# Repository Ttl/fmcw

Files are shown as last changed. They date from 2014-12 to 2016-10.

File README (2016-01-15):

Frequency modulated radar hardware, firmware and processing files.

For more information see:

http://hforsten.com/6-ghz-frequency-modulated-radar.html

and

http://hforsten.com/homemade-synthetic-aperture-radar.html

List of contents:

hardware: Contains KiCad schematic and board files. Made using KiCad version 2014-10-17 and might not open with a too old version.

firmware: Firmware for the Freescale Kinetis KL26Z microcontroller. Should be opened using Kinetis Design Studio (http://www.freescale.com/webapp/sps/site/prod_summary.jsp?code=KDS_IDE).

Firmware depends on mcuoneclipse components available at here: http://sourceforge.net/projects/mcuoneclipse/files/PEx%20Components/

processing: PC code for using the radar and processing the resulting data.
"fmcw.py" uses the radar and logs the data.
"fmcw_process.py" process the recorded data and plots time-range plot of them.
"list_plot.py" plots individual sweep captures from the recorded data for debugging purposes.

simulations: CST Microwave studio files.

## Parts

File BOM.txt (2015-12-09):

Digikey product codes

Capacitors:
10nF: 1276-1500-1-ND
0.5pF: 399-6157-1-ND
0.3pF: 399-6155-1-ND
100pF: 311-1024-1-ND
10pF: 1276-1139-1-ND
10uF: 311-1460-1-ND
2.2uF: 1276-1040-1-ND
4.7nF: 1276-1571-1-ND
1nF: 1276-1916-1-ND
22uF: 1276-2910-1-ND
1.8pF: 490-3089-1-ND
33pF: 1276-1272-1-ND
100n: 311-1697-1-ND

Inductors:
0.6nH: 445-3031-1-ND
1uH: 1276-6207-1-ND

Resistors:
1% tolerance
ATTENUATOR 7 DB 50 OHM 0805 SMD: PAT127CT-ND

Diodes:
DIODE SCHOTTKY 40V 0.2A SOT323: BAS40WT-TPCT-ND

Actives:
IC MIXER 4.5-9GHZ UP/DWN 8MSOP: 1127-1004-1-ND
IC RF PWR AMP 802.11A/N 16-QFN: SST11LP12-QCFCT-ND
IC MMIC VCO W/BUFF AMP 4X4QFN: 1127-1036-1-ND
IC AMP 5GHZ LNA 6QFN: 863-1398-1-ND

IC OPAMP GP 18MHZ RRO 16SSOP: LTC6242CGN#PBF-ND
IC OPAMP GP 215MHZ RRO TSOT23-6: LT6230CS6#TRMPBFCT-ND
IC OPAMP GP 1.4MHZ RRO SOT23-5: 497-7687-1-ND

IC REG MULTI CONFIG ADJ SOT23-6: 296-35223-1-ND
IC REG BUCK SYNC 3.3V SOT23-5: SC189ZSKCT-ND
IC REG LDO 3.3V 0.15A SC59-3: 863-1507-1-ND
IC REG LDO 3V 0.25A SOT23-3: MCP1700T-3002E/TTCT-ND

IC DGTL POT 10K 128TAPS SC70-6: MCP4017T-103E/LTCT-ND
IC MCU ARM 128KB FLASH 48QFN: MKL26Z128VFT4-ND
MOSFET P-CH 50V 130MA SOT-23: BSS84CT-ND
CRYSTAL 8MHZ 18PF SMD: 887-1448-1-ND

Connectors:
CONN SMA JACK 50 OHM EDGE MNT: CONSMA003.062-ND
SIL VERTICAL PC TAIL PIN HEADER: 952-2270-ND

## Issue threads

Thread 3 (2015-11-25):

Missing component libraries

penguin359, 2015-11-25:
It appears that a few components have changed since the 2014 release of the libraries and the pins of the new components don't match up. In particular, resistors and capacitors are shorter breaking the wire connections to the pins. The other components that are different are the four connectors used across the two sheets, wlan_radar.sch and mcu.sch. In the case of the connectors, it appears that their names have changed from CONN_2 and CONN_6 to CONN_01X02 and CONN_01X06. Updating the schematic files with the correct names makes the components show up, but their pin positions still don't line up so the wires have to be re-drawn.

I've re-attached all the wires to the appropriate pins to match with the updated components and the ERC now shows only three errors/warnings that appear have been there with the original schematic. However, I'd prefer to just keep the original schematic and it's library of components. Normally, a cached library, wlan_radar-cache.lib in this case, is created to house all the components used in a design. This allows the design to move across systems that might have a different set of libraries installed. Do you have a copy of the original library cache and can you include it in the Git repository so that the design files will still be intact regardless of the set of libraries installed on the local system?

Ttl, 2015-11-25:
I added the library cache file.

Closed 2015-11-25.

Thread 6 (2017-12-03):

radar range

mkeyno, 2017-12-03:
hi
sorry to open ticket for question , but have you run any test range ?what is the maximum of motion detection range ?
BR

Ttl, 2017-12-03:
Depends on the antennas but probably under 100 m even with good antennas.

This radar doesn't have very good performance and I don't recommend using it. See: https://github.com/Ttl/fmcw3 for a much better radar.

Closed 2017-12-03.

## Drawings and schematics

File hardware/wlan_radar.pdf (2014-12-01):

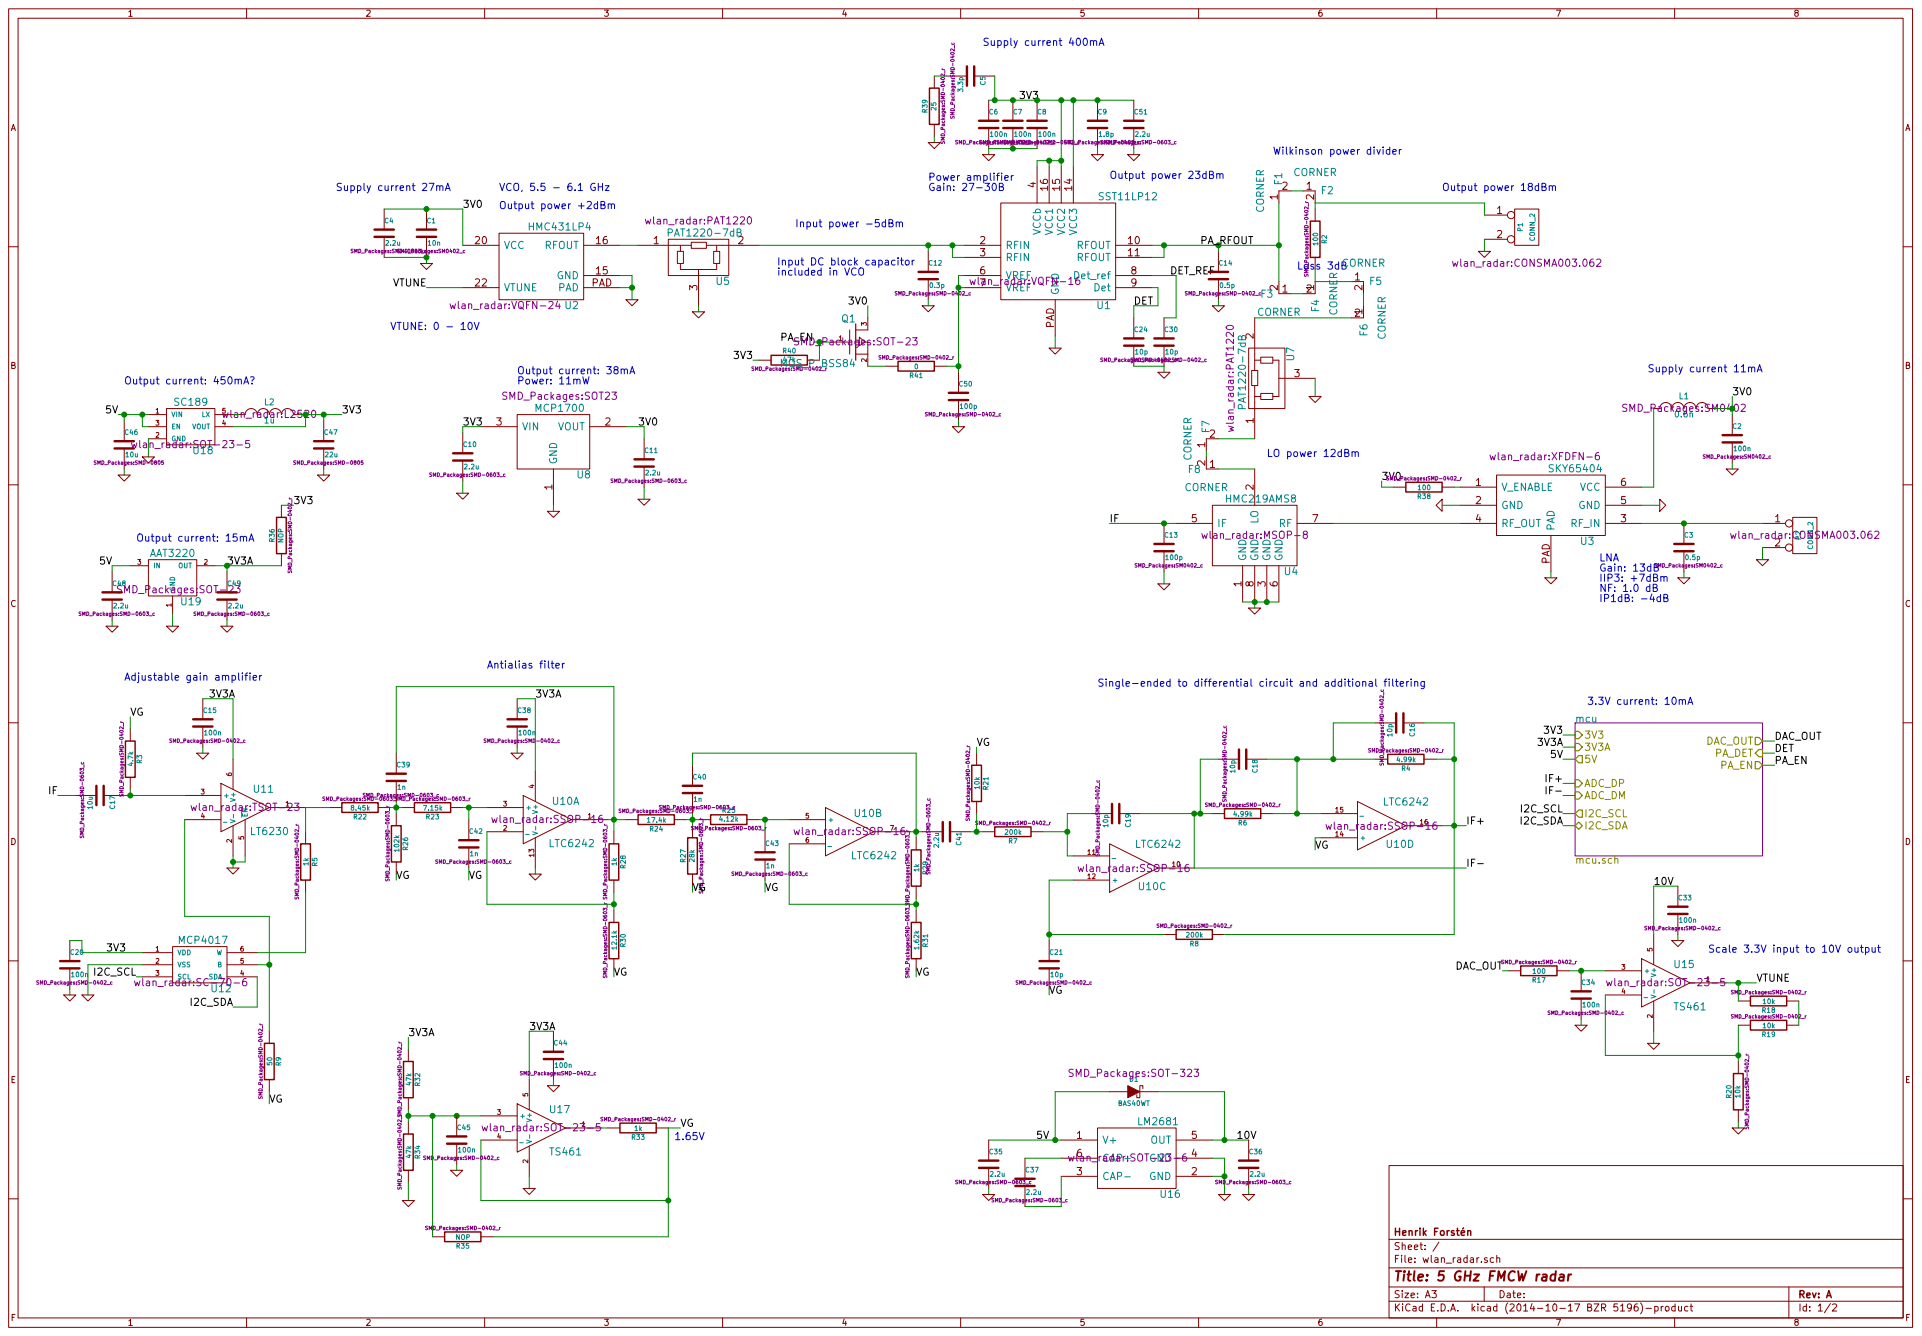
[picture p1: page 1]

4 VREF 6 VREF 7 Det_ref 8 Det 9 RFOUT 10 RFOUT 11 VCC3 14 VCC2 15 VCC1 16 GND PADU1SST11LP12

Input DC block capacitor
included in VCO

Scale 3.3V input to 10V output R17

File: wlan_radar.sch Sheet: / Henrik Forstén

Id: 1/2 Title: 5 GHz FMCW radar

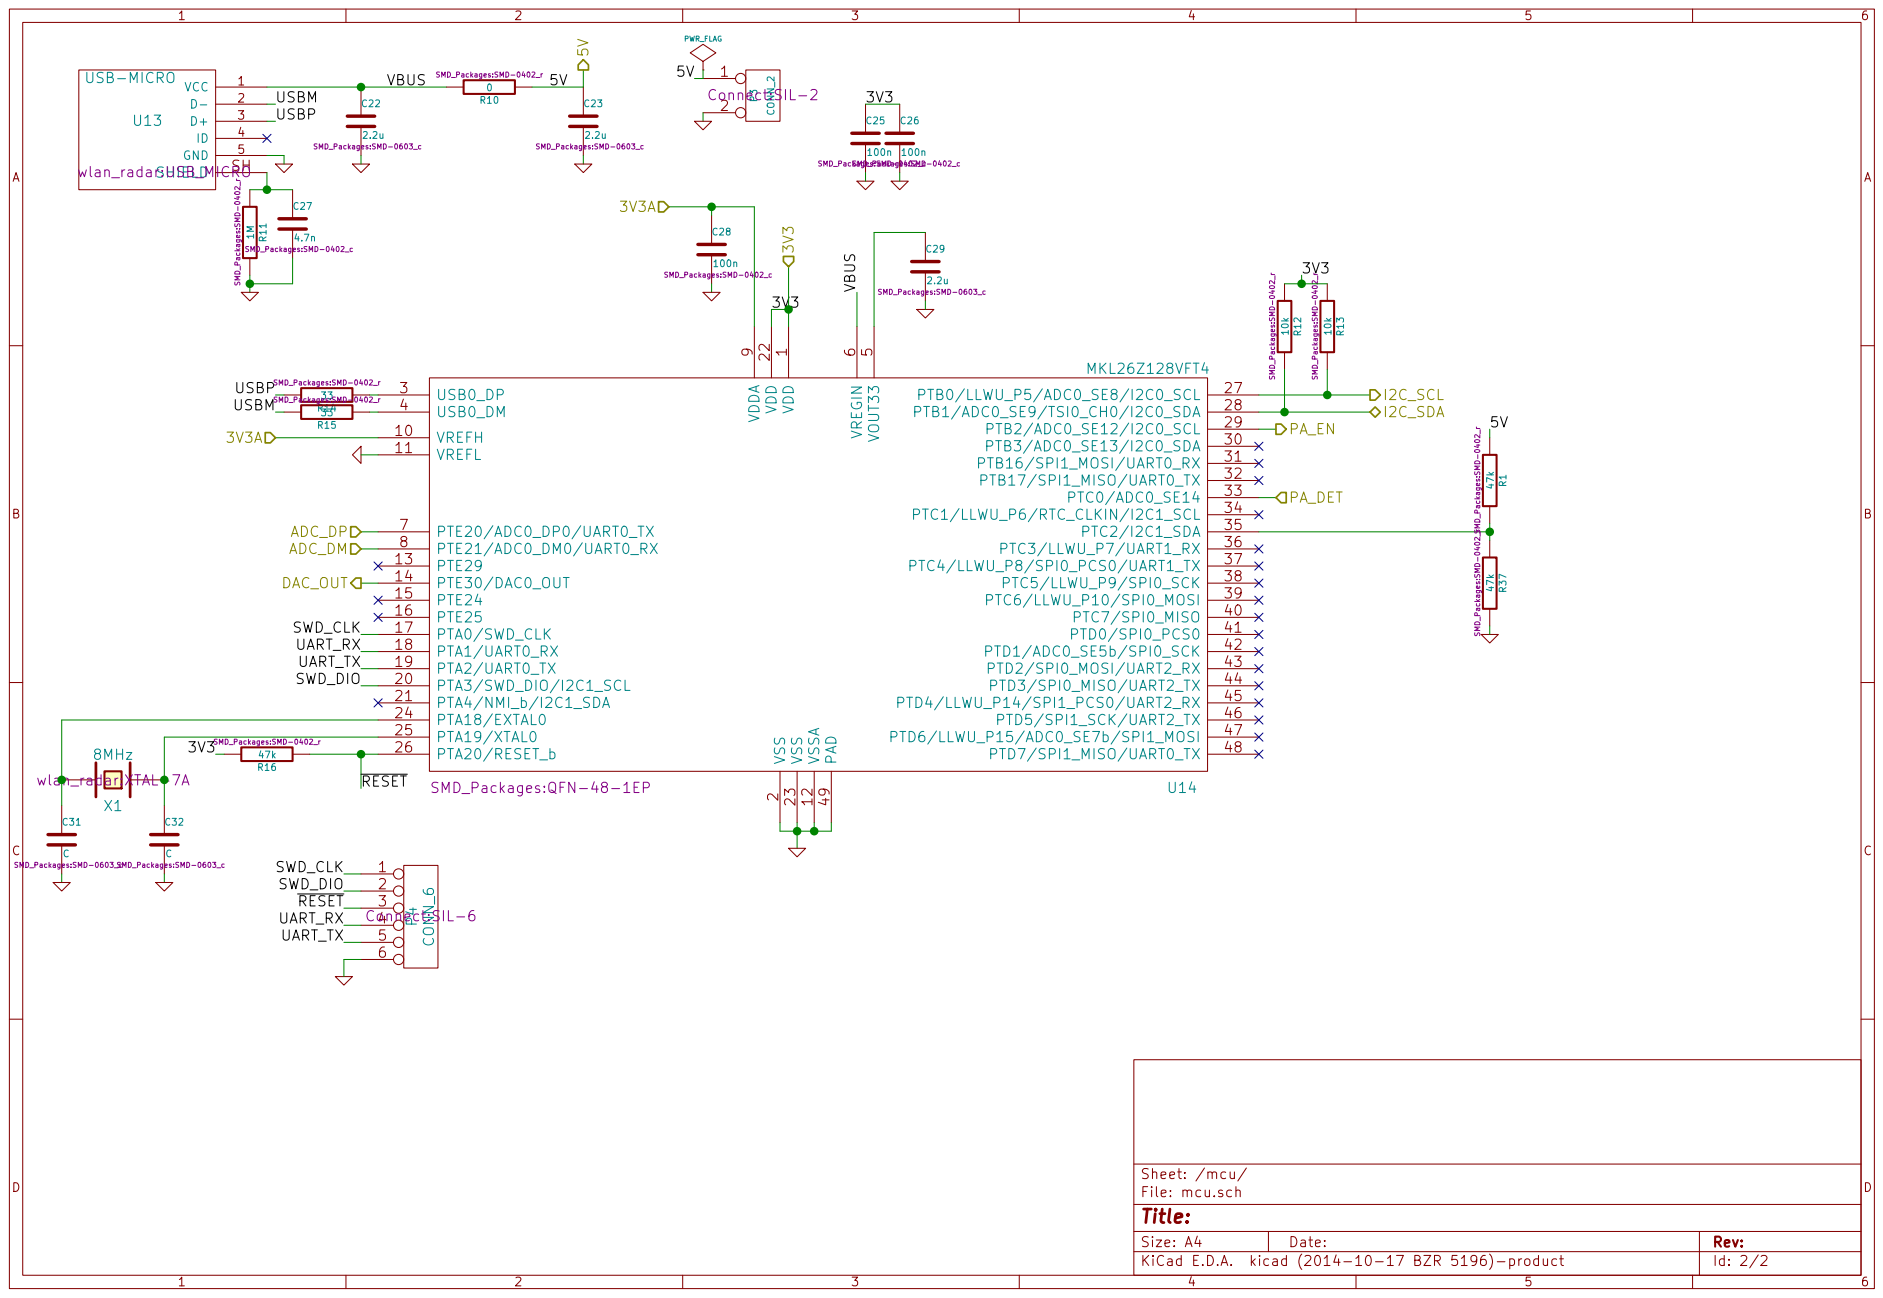
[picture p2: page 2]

9 VREFH 10 PTA3/SWD_DIO/I2C1_SCL 20 PTB3/ADC0_SE13/I2C0_SDA 30 PTC7/SPI0_MISO 40 VREFL 11 PTA4/NMI_b/I2C1_SDA 21 PTB16/SPI1_MOSI/UART0_RX 31 PTD0/SPI0_PCS0 41 VSSA 12 VDD 22

Id: 2/2 Title: File: mcu.sch Sheet: /mcu/ VDD

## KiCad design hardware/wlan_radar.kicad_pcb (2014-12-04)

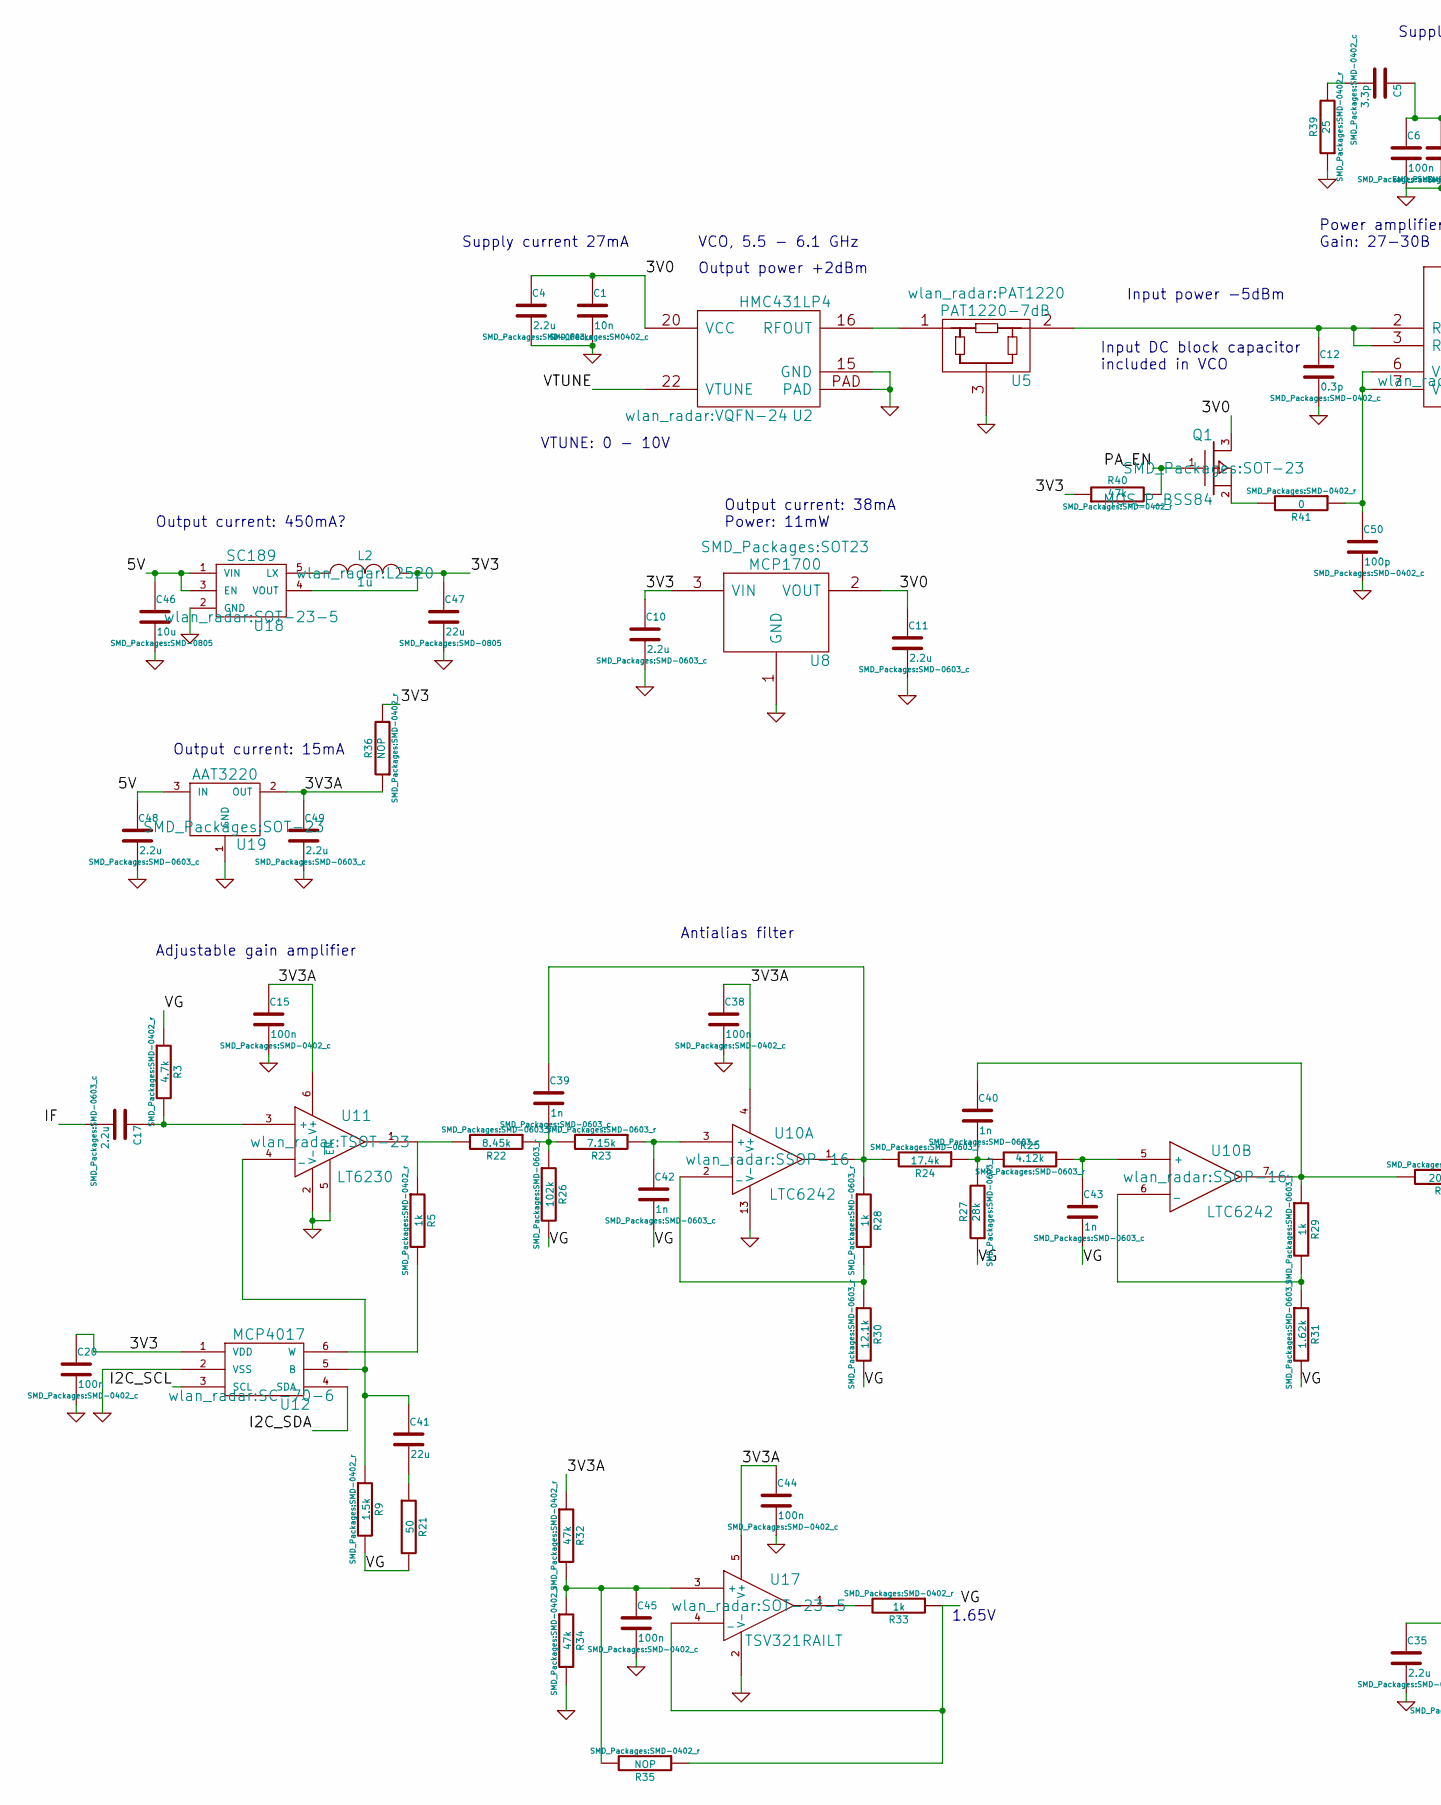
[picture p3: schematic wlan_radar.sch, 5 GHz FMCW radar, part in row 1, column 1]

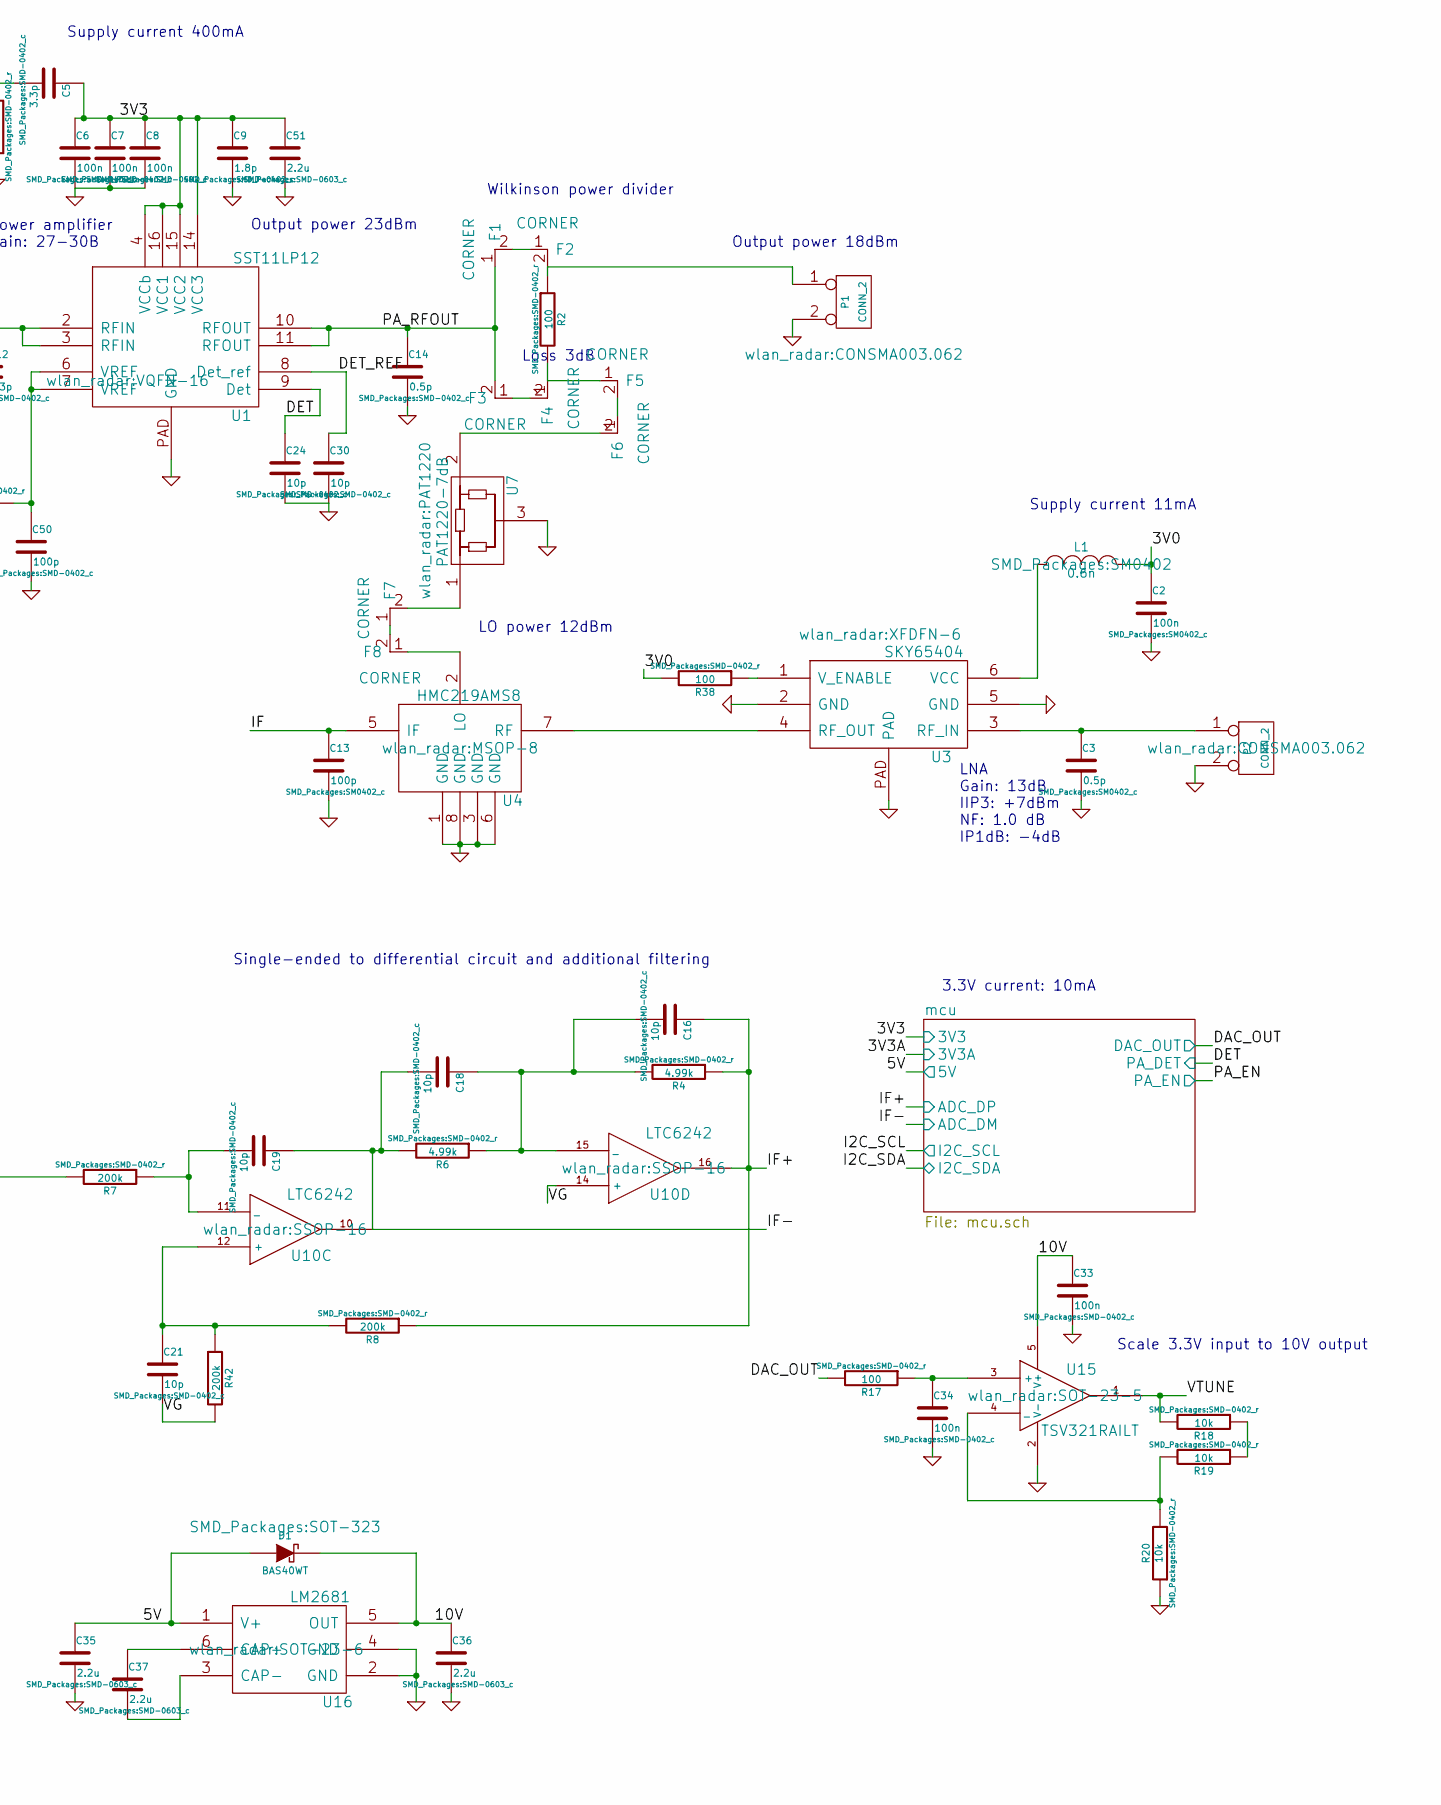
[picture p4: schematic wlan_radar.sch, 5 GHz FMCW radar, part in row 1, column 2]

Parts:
C1: 10n; SM0402_c
C2: 100n; SM0402_c
C3: 0.5p; SM0402_c
C4, C10, C11, C17, C35, C36, C37, C48, C49, C51: 2.2u; SMD-0603_c
C5: 3.3p; SMD-0402_c
C6, C7, C8, C15, C20, C33, C34, C38, C44, C45: 100n; SMD-0402_c
C9: 1.8p; SMD-0402_c
C12: 0.3p; SMD-0402_c
C13: 100p; SM0402_c
C14: 0.5p; SMD-0402_c
C16, C18, C19, C21, C24, C30: 10p; SMD-0402_c
C39, C40, C42, C43: 1n; SMD-0603_c
C41, C47: 22u; SMD-0805
C46: 10u; SMD-0805
C50: 100p; SMD-0402_c
D1: BAS40WT; SOT-323
F1, F2, F3, F4: CORNER; miter_0.179_90deg
F5, F6, F7, F8: CORNER; MITER_0.350mm_90deg
L1: 0.6n; SM0402
L2: 1u; L2520
P1, P2: CONN_2; CONSMA003.062
Q1: MOS_P_BSS84; SOT-23
R2, R17, R38: 100; SMD-0402_r
R3: 4.7k; SMD-0402_r
R4, R6: 4.99k; SMD-0402_r
R5, R33: 1k; SMD-0402_r
R7, R8, R42: 200k; SMD-0402_r
R9: 1.5k; SMD-0402_r
R18, R19, R20: 10k; SMD-0402_r
R21: 50; SMD-0402_r
R22: 8.45k; SMD-0603_r
R23: 7.15k; SMD-0603_r
R24: 17.4k; SMD-0603_r
R25: 4.12k; SMD-0603_r
R26: 102k; SMD-0603_r
R27: 28k; SMD-0603_r
R28, R29: 1k; SMD-0603_r
R30: 12.1k; SMD-0603_r
R31: 1.62k; SMD-0603_r
R32, R34, R40: 47k; SMD-0402_r
R35, R36: NOP; SMD-0402_r
R39: 25; SMD-0402_r
R41: 0; SMD-0402_r
U1: SST11LP12; VQFN-16
U2: HMC431LP4; VQFN-24
U3: SKY65404; XFDFN-6
U4: HMC219AMS8; MSOP-8
U5, U7: PAT1220-7dB; PAT1220
U8: MCP1700; SOT23
U10: LTC6242; SSOP-16
U11: LT6230; TSOT-23
U12: MCP4017; SC-70-6
U15, U17: TSV321RAILT; SOT-23-5
U16: LM2681; SOT-23-6
U18: SC189; SOT-23-5
U19: AAT3220; SOT-23

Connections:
/3V0: C1.1, C2.1, C4.1, C11.1, L1.2, Q1.3 (D), R38.2, U2.20 (VCC), U8.2 (VOUT)
/10V: C33.1, C36.1, D1.3 (K), U15.5 (V+), U16.5 (OUT)
/DET_REF: C30.1, U1.8 (Det_ref)
/IF: C13.1, C17.2, U4.5 (IF)
/PA_RFOUT: C14.1, F1.1, F3.2, U1.10 (RFOUT), U1.11 (RFOUT)
/VG: C21.2, C42.2, C43.2, R3.1, R9.2, R21.2, R26.2, R27.1, R30.2, R31.2, R33.1, R35.1, R42.2, U10.14 (+), U17.4 (_)
/VTUNE: R18.2, U2.22 (VTUNE), U15.1
/mcu/3V3: C5.1, C6.1, C7.1, C8.1, C9.1, C10.1, C20.1, C47.1, C51.1, L2.2, R36.2, R40.1, U1.4 (VCCb), U1.14 (VCC3), U1.15 (VCC2), U1.16 (VCC1), U8.3 (VIN), U12.1 (VDD), U18.4 (VOUT); also elsewhere on the board
/mcu/3V3A: C15.1, C38.1, C44.1, C49.1, R32.1, R36.1, U10.4 (V+), U11.6 (V+), U17.5 (V+), U19.2 (OUT); also elsewhere on the board
/mcu/5V: C35.1, C46.1, C48.1, D1.1 (A), U16.1 (V+), U18.1 (VIN), U18.3 (EN), U19.3 (IN); also elsewhere on the board
/mcu/ADC_DM: C18.2, C19.1, R6.2, U10.10; also elsewhere on the board
/mcu/ADC_DP: C16.1, R4.1, R8.1, U10.16; also elsewhere on the board
/mcu/DAC_OUT: R17.2; also elsewhere on the board
/mcu/I2C_SCL: U12.3 (SCL); also elsewhere on the board
/mcu/I2C_SDA: U12.4 (SDA); also elsewhere on the board
/mcu/PA_DET: C24.1, U1.9 (Det); also elsewhere on the board
/mcu/PA_EN: Q1.1 (G), R40.2; also elsewhere on the board
GND: C1.2, C2.2, C3.2, C4.2, C6.2, C7.2, C8.2, C9.2, C10.2, C11.2, C12.2, C13.2, C14.2, C15.2, C20.2, C24.2, C30.2, C33.2, C34.2, C35.2, C36.2, C38.2, C44.2, C45.2, C46.2, C47.2, C48.2, C49.2, C50.2, C51.2, P1.2 (PM), P2.2 (PM), R20.1, R34.2, R39.1, U1.PAD (GND), U2.15 (GND), U2.PAD, U3.2 (GND), U3.5 (GND), U3.PAD, U4.1 (GND), U4.3 (GND), U4.6 (GND), U4.8 (GND), U5.3, U7.3, U8.1 (GND), U10.13 (V-), U11.2 (V-), U11.5 (~EN), U12.2 (VSS), U15.2 (V-), U16.2 (GND), U16.4 (GND), U17.2 (V-), U18.2 (GND), U19.1 (GND); also elsewhere on the board
unnamed: C3.1, P2.1, U3.3 (RF_IN)
unnamed: C5.2, R39.2
unnamed: C12.1, U1.2 (RFIN), U1.3 (RFIN), U5.2
unnamed: C16.2, C18.1, R4.2, R6.1, U10.15 (_)
unnamed: C17.1, R3.2, U11.3 (+)
unnamed: C19.2, R7.1, U10.11 (_)
unnamed: C21.1, R8.2, R42.1, U10.12 (+)
unnamed: C34.1, R17.1, U15.3 (+)
unnamed: C37.1, U16.6 (CAP+)
unnamed: C37.2, U16.3 (CAP-)
unnamed: C39.1, R24.2, R28.1, U10.1
unnamed: C39.2, R22.1, R23.2, R26.1
unnamed: C40.1, R7.2, R29.1, U10.7
unnamed: C40.2, R24.1, R25.1, R27.2
unnamed: C41.1, R9.1, U11.4 (_), U12.5 (B)
unnamed: C41.2, R21.1
unnamed: C42.1, R23.1, U10.3 (+)
unnamed: C43.1, R25.2, U10.5 (+)
unnamed: C45.1, R32.2, R34.1, R35.2, U17.3 (+)
unnamed: C50.1, R41.1, U1.6 (VREF), U1.7 (VREF)
unnamed: F1.2, F2.1
unnamed: F2.2, P1.1, R2.1
unnamed: F3.1, F4.2
unnamed: F4.1, F5.1, R2.2
unnamed: F5.2, F6.1
unnamed: F6.2, U7.2
unnamed: F7.1, F8.2
unnamed: F7.2, U7.1
unnamed: F8.1, U4.2 (LO)
unnamed: L1.1, U3.6 (VCC)
unnamed: L2.1, U18.5 (LX)
unnamed: Q1.2 (S), R41.2
unnamed: R5.2, U12.6 (W)
unnamed: R18.1, R19.1
unnamed: R19.2, R20.2, U15.4 (_)
unnamed: R5.1, R22.2, U11.1
unnamed: R28.2, R30.1, U10.2 (_)
unnamed: R29.2, R31.1, U10.6 (_)
unnamed: R33.2, U17.1
unnamed: R38.1, U3.1 (V_ENABLE)
unnamed: U2.16 (RFOUT), U5.1
unnamed: U3.4 (RF_OUT), U4.7 (RF)

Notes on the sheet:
VCO, 5.5 - 6.1 GHz
Output power +2dBm
Wilkinson power divider
Power amplifier Gain: 27-30B
Input power -5dBm
Output power 23dBm
Loss 3dB
Output power 18dBm
LO power 12dBm
LNA Gain: 13dB IIP3: +7dBm NF: 1.0 dB IP1dB: -4dB
Supply current 400mA
Supply current 27mA
VTUNE: 0 - 10V
Supply current 11mA
Output current: 38mA Power: 11mW
Scale 3.3V input to 10V output
1.65V
Adjustable gain amplifier
Antialias filter
Single-ended to differential circuit and additional filtering
Output current: 15mA
Output current: 450mA?
Input DC block capacitor included in VCO
3.3V current: 10mA

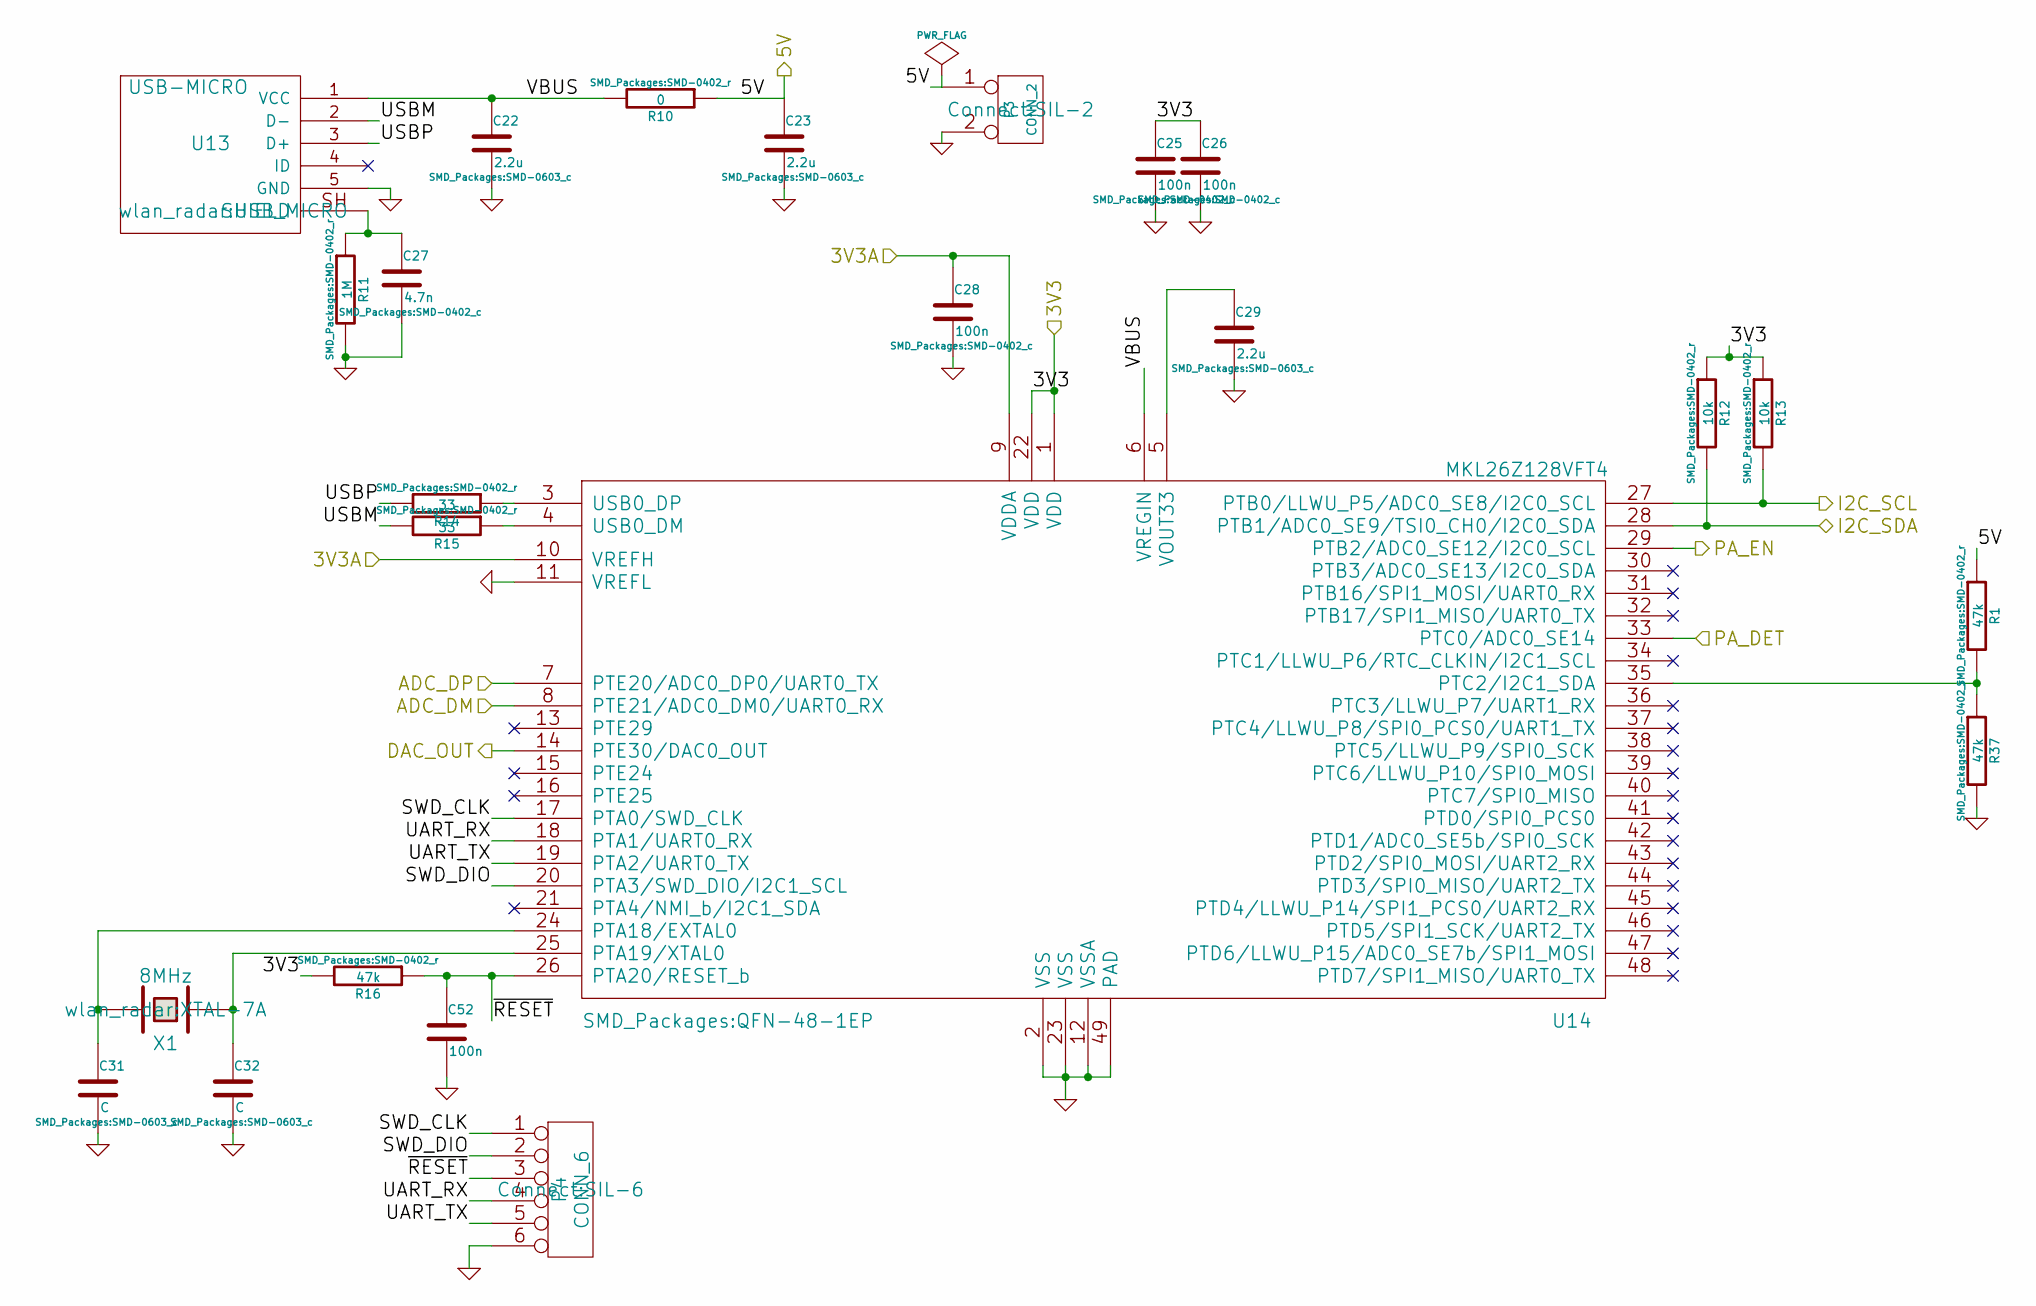
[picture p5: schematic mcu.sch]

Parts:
C22, C23, C29: 2.2u; SMD-0603_c
C25, C26, C28, C52: 100n; SMD-0402_c
C27: 4.7n; SMD-0402_c
C31, C32: C; SMD-0603_c
P3: CONN_2; SIL-2
P4: CONN_6; SIL-6
R1, R16, R37: 47k; SMD-0402_r
R10: 0; SMD-0402_r
R11: 1M; SMD-0402_r
R12, R13: 10k; SMD-0402_r
R14, R15: 33; SMD-0402_r
U13: USB-MICRO; USB_MICRO
U14: MKL26Z128VFT4; QFN-48-1EP
X1: 8MHz; XTAL-7A

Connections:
/mcu/3V3: C25.1, C26.1, R12.1, R13.1, R16.2, U14.1 (VDD), U14.22 (VDD); also elsewhere on the board
/mcu/3V3A: C28.1, U14.9 (VDDA), U14.10 (VREFH); also elsewhere on the board
/mcu/5V: C23.1, P3.1, R1.1, R10.1; also elsewhere on the board
/mcu/ADC_DM: U14.8 (PTE21/ADC0_DM0/UART0_RX); also elsewhere on the board
/mcu/ADC_DP: U14.7 (PTE20/ADC0_DP0/UART0_TX); also elsewhere on the board
/mcu/DAC_OUT: U14.14 (PTE30/DAC0_OUT); also elsewhere on the board
/mcu/I2C_SCL: R13.2, U14.27 (PTB0/LLWU_P5/ADC0_SE8/I2C0_SCL); also elsewhere on the board
/mcu/I2C_SDA: R12.2, U14.28 (PTB1/ADC0_SE9/TSI0_CH0/I2C0_SDA); also elsewhere on the board
/mcu/PA_DET: U14.33 (PTC0/ADC0_SE14); also elsewhere on the board
/mcu/PA_EN: U14.29 (PTB2/ADC0_SE12/I2C0_SCL); also elsewhere on the board
/mcu/SWD_CLK: P4.1, U14.17 (PTA0/SWD_CLK)
/mcu/SWD_DIO: P4.2, U14.20 (PTA3/SWD_DIO/I2C1_SCL)
/mcu/UART_RX: P4.4, U14.18 (PTA1/UART0_RX)
/mcu/UART_TX: P4.5, U14.19 (PTA2/UART0_TX)
/mcu/USBM: R15.2, U13.2 (D-)
/mcu/USBP: R14.2, U13.3 (D+)
/mcu/VBUS: C22.1, R10.2, U13.1 (VCC), U14.6 (VREGIN)
/mcu/~RESET: C52.1, P4.3, R16.1, U14.26 (PTA20/RESET_b)
GND: C22.2, C23.2, C25.2, C26.2, C27.2, C28.2, C29.2, C31.2, C32.2, C52.2, P3.2 (PM), P4.6, R11.2, R37.2, U13.5 (GND), U14.2 (VSS), U14.11 (VREFL), U14.12 (VSSA), U14.23 (VSS), U14.49 (PAD); also elsewhere on the board
unnamed: C27.1, R11.1, U13.SH (SHIELD)
unnamed: C29.1, U14.5 (VOUT33)
unnamed: C31.1, U14.24 (PTA18/EXTAL0), X1.2
unnamed: C32.1, U14.25 (PTA19/XTAL0), X1.1
unnamed: R1.2, R37.1, U14.35 (PTC2/I2C1_SDA)
unnamed: R14.1, U14.3 (USB0_DP)
unnamed: R15.1, U14.4 (USB0_DM)

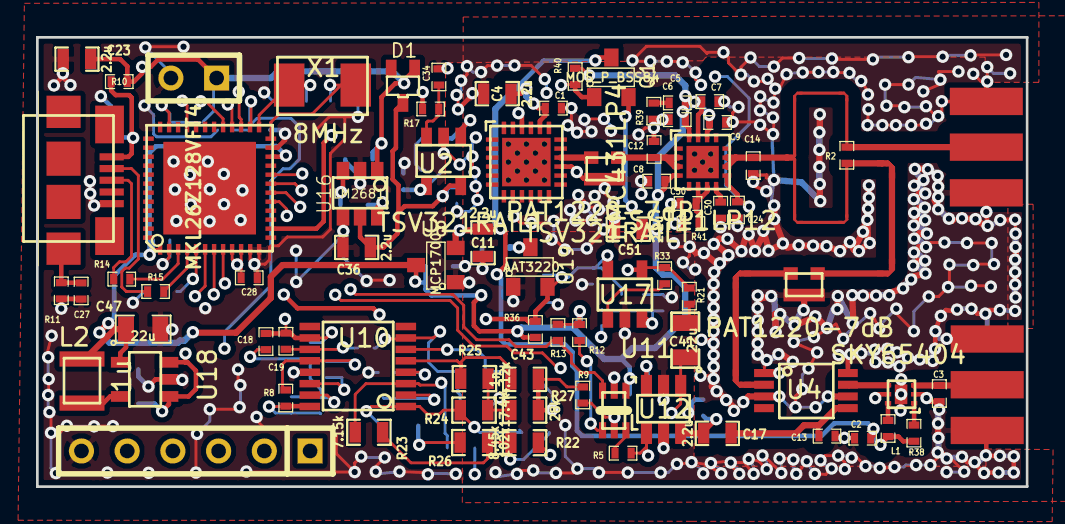
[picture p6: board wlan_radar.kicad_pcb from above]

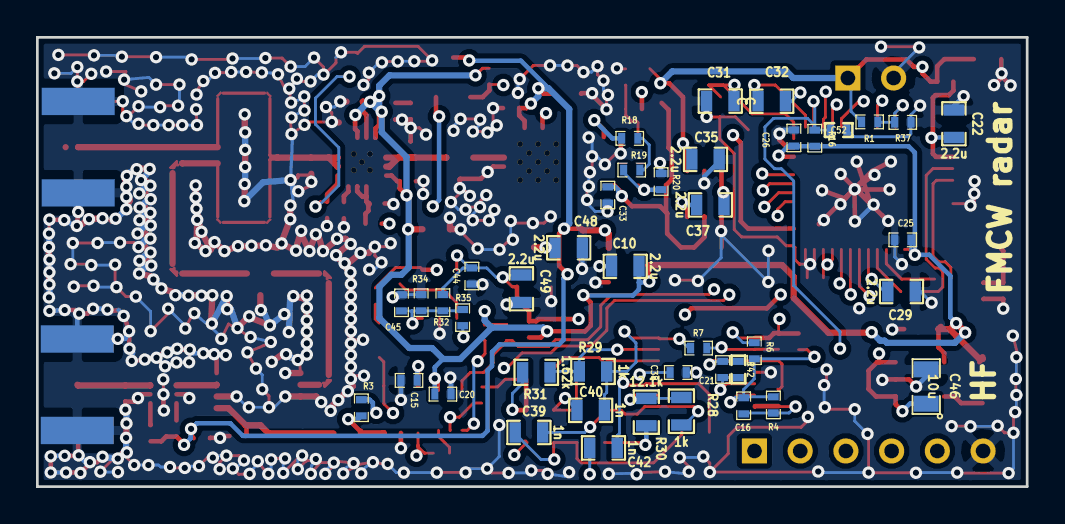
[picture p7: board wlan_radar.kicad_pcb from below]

Board: 4 copper layers, 55.0 x 25.0 mm, 128 parts (42 on the bottom side), 75 nets.

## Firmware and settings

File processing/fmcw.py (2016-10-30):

from datetime import datetime
import time
import math
import sys
import serial
import numpy as np
import matplotlib.pyplot as plt
import matplotlib.animation as animation
from scipy import interpolate
from Queue import Queue
from threading import Thread

BAUDRATE = 200

def get_measure(ser, queue):
    while True:
        i = 0
        while ser.inWaiting() == 0 and i < 500:
            time.sleep(0.01)
            i += 1
        if i >= 500:
            raise Exception("Measure failed")
        d = []
        while True:
            c = ser.read(1)
            if c == 'M':
                break
        #Gain
        c_mcp = ord(ser.read(1))

        #Number of points
        c = ser.read(2)
        points = (ord(c[0])<<8)|ord(c[1])
        overflows = 0
        abs_max = 0
        prev_c = 0
        while points > 0:
            if 1:
                if len(d) == 0:
                    c = ser.read(2)
                    uint = (ord(c[0])<<8)|ord(c[1])
                else:
                    c = ser.read(1)
                    #Reassemble int
                    uint = ord(c)
                    #Overflow, reading 16 bits
                    if uint == 128:
                        overflows +=1
                        c = ser.read(2)
                        uint = (ord(c[0])<<8)|ord(c[1])
                    else:
                        if uint > 127:
                            uint = -(256-uint)
                        uint *= 2
                        uint += prev_c
                prev_c = uint
                v = abs(uint-32768)
                if v > abs_max:
                    abs_max = v
                d.append(uint/float(2**16)-0.5)
                points -= 1
            else:
                c = ser.read(2)
                #Reassemble int
                uint = (ord(c[0])<<8)|ord(c[1])
                #d.append(uint)
                d.append(uint/float(2**16)-0.5)
                points -= 1
        queue.put((points,c_mcp,d))


class DopplerAnalogPlot:
    def __init__(self, f, sample_rate, freq, interp=False, interp_points=600, logging=False):
        self.f = f
        self.sample_rate = sample_rate
        self.freq = freq
        self.interp = interp
        self.interp_points = interp_points
        self.logging = logging
        if self.logging != False:
            self.log_file = open(self.logging+datetime.now().strftime('%Y-%m-%dT%H-%M.log'), "w")

    def update(self, frameNum, pt, pf, axt, axf):
        mcp,y = self.f()
        if len(y) == 0:
            y = [0]

        if self.logging:
            self.log_file.write(str(time.time())+';')
            self.log_file.write(str(mcp)+';')
            self.log_file.write(','.join(map(str,y)))
            self.log_file.write('\n')
            self.log_file.flush()

        pt.set_ydata(y)
        pt.set_xdata(range(len(y)))
        axt.set_xlim(0,len(y))

        miny = min(y)
        maxy = max(y)
        miny = 1.1*miny if miny<0 else 0.9*miny
        maxy = 0.9*maxy if maxy<0 else 1.1*maxy
        axt.set_ylim(miny,maxy)

        yf,xf = fft(y, self.sample_rate, np.hamming)

        #Frequency to speed conversion
        xf = [3e8*i/(2*self.freq) for i in xf]

        yf, xf = yf[:100], xf[:100]

        if self.interp and self.interp_points:
            fint = interpolate.interp1d(xf, yf, kind=self.interp)
            xnew = np.linspace(xf[0], xf[-1], self.interp_points)
            ynew = [fint(xi) for xi in xnew]
            pf.set_ydata(ynew)
            pf.set_xdata(xnew)
            axf.set_xlim(0,xnew[-1])
            axf.set_ylim(1,max(ynew))
            m = max(ynew)
            i = ynew.index(m)
            print "Speed",xnew[i],"m/s"
        else:
            pf.set_ydata(yf)
            pf.set_xdata(xf)
            axf.set_xlim(0,xf[-1])
            axf.set_ylim(min(yf),max(yf))
        return (pt,pf,axt,axf)

class FMCWAnalogPlot:
    def __init__(self, f, sample_rate, freq_start, freq_end, sweep_length, interp=False, interp_points=600, logging=False):
        self.f = f
        self.sample_rate = sample_rate
        self.freq_start = freq_start
        self.freq_end = freq_end
        self.bandwidth = freq_end - freq_start
        self.sweep_length = sweep_length
        self.interp = interp
        self.interp_points = interp_points
        self.logging = logging
        if self.logging != False:
            self.log_file = open(self.logging+datetime.now().strftime('%Y-%m-%dT%H-%M.log'), "w")

        self.t_start = None

    def update(self, frameNum, pt, pf, axt, axf):
        mcp,y = self.f()
        t_stop = time.time()
        if self.t_start != None:
            print "Update rate {} Hz".format(1/(t_stop-self.t_start))
        self.t_start = t_stop
        if len(y) == 0:
            y = [0]


        if self.logging:
            self.log_file.write(str(time.time())+';')
            self.log_file.write(str(mcp)+';')
            self.log_file.write(','.join(map(str,y)))
            self.log_file.write('\n')
            self.log_file.flush()

        #Convert to float
        #y = [yi/float(2**16)-0.5 for yi in y]
        #y = [y[i]-y0[i] for i in xrange(min(len(y),len(y0)))]

        pt.set_ydata(y)
        pt.set_xdata(range(len(y)))
        axt.set_xlim(0,len(y))
        miny = min(y)
        maxy = max(y)
        miny = 1.1*miny if miny<0 else 0.9*miny
        maxy = 0.9*maxy if maxy<0 else 1.1*maxy
        axt.set_ylim(miny, maxy)

        yf,xf = fft(y, self.sample_rate, np.hamming)

        yf = yf[:100]
        xf = xf[:100]

        #Frequency to range conversion
        xf = [3e8*i*self.sweep_length/(2*self.bandwidth) for i in xf]

        if self.interp and self.interp_points:
            fint = interpolate.interp1d(xf, yf, kind=self.interp)
            xnew = np.linspace(xf[0], xf[-1], self.interp_points)
            ynew = [20*math.log10(fint(xi)) if fint(xi)>0 else -80 for xi in xnew]
            pf.set_ydata(ynew)
            pf.set_xdata(xnew)
            axf.set_xlim(xnew[0],xnew[-1])
            axf.set_ylim(-80,max(ynew))
            m = max(ynew)
            i = ynew.index(m)
            print "Distance",xnew[i],"m"
        else:
            yf = [20*math.log10(yi) if yi>0 else -80 for yi in yf]
            pf.set_ydata(yf)
            pf.set_xdata(xf)
            axf.set_xlim(0,xf[-1])
            axf.set_ylim(-80,max(yf))
        #print time.time()-t_start
        return (pt,pf,axt,axf)

#Configures serial port
def configure_serial(serial_port):
    return serial.Serial(
        port=serial_port,
        baudrate=BAUDRATE,
        parity=serial.PARITY_NONE,
        stopbits=serial.STOPBITS_TWO,
        bytesize=serial.EIGHTBITS,
        timeout=0.1
    )

def fft(data, sample_rate, window=None):
    if window:
        w = window(len(data))
        data = [data[i]*w[i] for i in xrange(len(w))]
    fs = 0.5/float(sample_rate)
    y = map(abs,np.fft.rfft(data))
    fstep = fs/len(y)
    return (y,[fstep*i for i in xrange(0,len(y))])

def write_delay(ser, data, delay):
    for c in data:
        ser.write(c)
        time.sleep(delay)

class Radar():
    def __init__(self, ser):
        self.ser = ser
        self.log = open("fmcw.log","a")
        self.mode = None
        self.m_queue = Queue(2)
        self.m_thread = None


    def pa_on(self):
        ser.write('O')
        return ser.readline() == "PA ON\r\n"

    def pa_off(self):
        ser.write('o')
        return ser.readline() == "PA OFF\r\n"

    def set_gain(self, val):
        if val < 0x00 or val > 0x7F:
            raise ValueError("Invalid potentiometer value")
        write_delay(ser, 'R'+chr(val), 2e-3)
        ret = ser.read(1)
        return ret

    def set_mode(self, mode):
        self.mode = mode
        if mode == "FMCW":
            ser.write('F')
        elif mode == "DOPPLER":
            ser.write('D')
        return False

    def mcp_to_gain(self, val):
        """Convert potentiometer value to gain"""
        r1 = 50.0
        r2 = 1500.0
        mcp_range = 10e3
        var_r = (float(val)/255)*mcp_range+r2
        return (1+var_r/r1)

    def set_sweep_start(self, val):
        write_delay(ser, 's'+chr(val>>8)+chr(val&0xFF), 2e-3)

    def set_sweep_stop(self, val):
        write_delay(ser, 'M'+chr(val>>8)+chr(val&0xFF), 2e-3)

    def meas_toggle(self):
        ser.write('m')
        if self.m_thread == None:
            self.m_thread = Thread(target=get_measure, args=(ser,self.m_queue))
            self.m_thread.start()
        else:
            self.m_thread.join(0)
            self.m_thread = None

    def measure(self):
        if self.m_thread == None:
            self.meas_toggle()
        points, c_mcp, d = self.m_queue.get(True)
        if self.log != None:
            self.log.write(str(points)+':')
            self.log.write(','.join(map(str,d)))
            self.log.write('\n')
        print c_mcp
        return (c_mcp,d)


if __name__ == "__main__":
    device = sys.argv[1]
    try:
        ser = configure_serial(device)
        if not ser.isOpen():
            raise Exception
    except:
        print 'Opening serial port {} failed.'.format(device)
        exit(1)

    try:
        radar = Radar(ser)
        time.sleep(0.1)

        while ser.inWaiting() > 0:
            ser.read(ser.inWaiting())

        if not radar.pa_on():
            print "Enabling PA failed"
            exit(1)
        radar.set_mode("FMCW")
        #radar.set_mode("DOPPLER")

        fig, (axt, axf) = plt.subplots(2)
        pt, = axt.plot([],[])
        pf, = axf.plot([],[])

        radar.meas_toggle()

        if radar.mode == "DOPPLER":
            analogPlot = DopplerAnalogPlot(radar.measure, 4.45e-6, 6e9, None, 1000, logging='doppler')
            anim = animation.FuncAnimation(fig, analogPlot.update,
                                             fargs=(pt,pf,axt,axf),
                                             interval=1)
        else:
            analogPlot = FMCWAnalogPlot(radar.measure, 24e-6, 5.99e9, 6.1e9, 20e-6*(1000)/1., None, 1000, logging='fmcw')
            anim = animation.FuncAnimation(fig, analogPlot.update,
                                             fargs=(pt,pf,axt,axf),
                                             interval=1)
        plt.show()

    finally:
        radar.meas_toggle()
        ser.close()

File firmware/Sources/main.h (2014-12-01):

/*
 * main.h
 *
 *  Created on: Oct 9, 2014
 *      Author: Henrik
 */

#ifndef MAIN_H_
#define MAIN_H_

extern volatile uint16_t dac_out;
extern uint8_t adc_err;
extern volatile uint8_t meas_start;

/* RUN, measurement running.
 * END, measurement ended, but data not transferred
 * STOP, data transferred.
 */
typedef volatile enum {START, RUN, END, STOP} meas_enum;
typedef volatile enum {DOPPLER, FMCW} radar_enum;

extern meas_enum meas_status;
extern radar_enum radar_mode;

extern volatile uint16_t dac_min;
extern volatile uint16_t dac_max;

//#define DAC_MIN 819 //2V = 5.6GHz
#define DAC_MIN_INIT 2257
#define DAC_MAX_INIT 2757
#define DAC_STEP 1
#define SAWTOOTH

#define ADC_BUFF_SIZE 3000
#define DOPPLER_LENGTH 2000

#define AUTOGAIN


extern uint16_t adc_buff[ADC_BUFF_SIZE];
extern volatile uint16_t adc_buff_i;

void stop_meas(void);
void start_meas(void);

#endif /* MAIN_H_ */

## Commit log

2014-12-04 Fix hardware mistakes
    This commit adds fixes some of the mistakes identified after the
    board was ordered.
    Add 100n capacitor to MCUs reset pin to fix programming issues.
    Add series connection of resistor and capacitor in parallel
    with mixer output amplifier to fix the DC balance issue.
    Remove the now unneeded capacitor and resistor
    after the low-pass filter.
    Add 200k resistor in feedback path of single-ended to differential
    conversion circuit to solve the issue with limited input voltage range.
    [mcu.sch, wlan_radar.kicad_pcb, wlan_radar.sch]
2014-12-30 Add bill of materials
2014-12-30 Use non-zero update interval
    0 interval doesn't work on my laptop though desktop computer
    is fine with it.
    [fmcw.py]
2015-08-10 Don't throw away samples
    Due to discontinuity in the sweep there can be a big spike
    in the amplitude at the beginning of the sweep. Now first
    third of the samples are not taken into consideration in autogain
    algorithm.
    Reduce ADC sampling rate, because previous one was too high considering
    the maximum range of the radar.
2015-12-09 Assign values to crystal load capacitors (33p)
    Add 100n capacitors to BOM
    [mcu.sch]
